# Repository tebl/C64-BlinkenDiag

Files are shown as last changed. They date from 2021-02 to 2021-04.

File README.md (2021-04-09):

# C64 BlinkenDiag
I was halfway through sketching out a new PCB based on the details found in an article on [tech.guitarsite.de](http://tech.guitarsite.de/c64_diag_dt_cart.html) before realizing it was already a PCB mentioned at the bottom, more specifically the one by [Diag64cart](https://github.com/svenpetersen1965/Diag64cart) by Sven Petersen (in turn based on [VersaCart64](https://github.com/bwack/Versa64Cart). I did however choose to introduce a few simple features of my own, mainly adding the option of disabling ROM boot - the method used was based on details found on [markus.brenner.de/cartridge](http://markus.brenner.de/cartridge). Secondly, I added a lot of LEDs in the hope that it might in some way be used to detect bus errors.

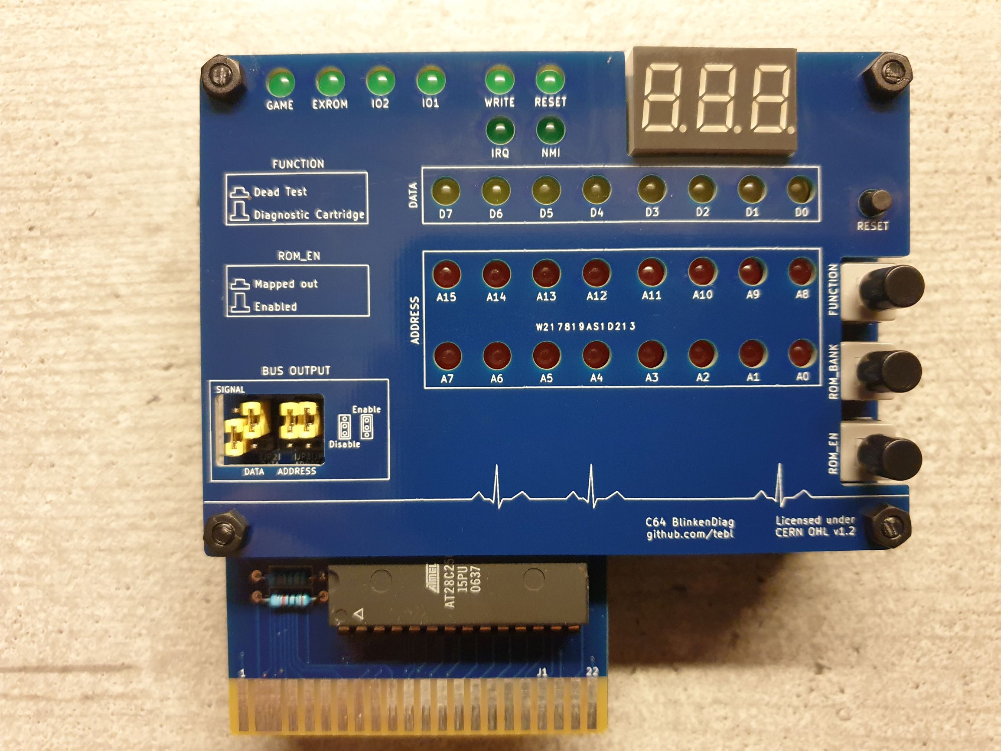
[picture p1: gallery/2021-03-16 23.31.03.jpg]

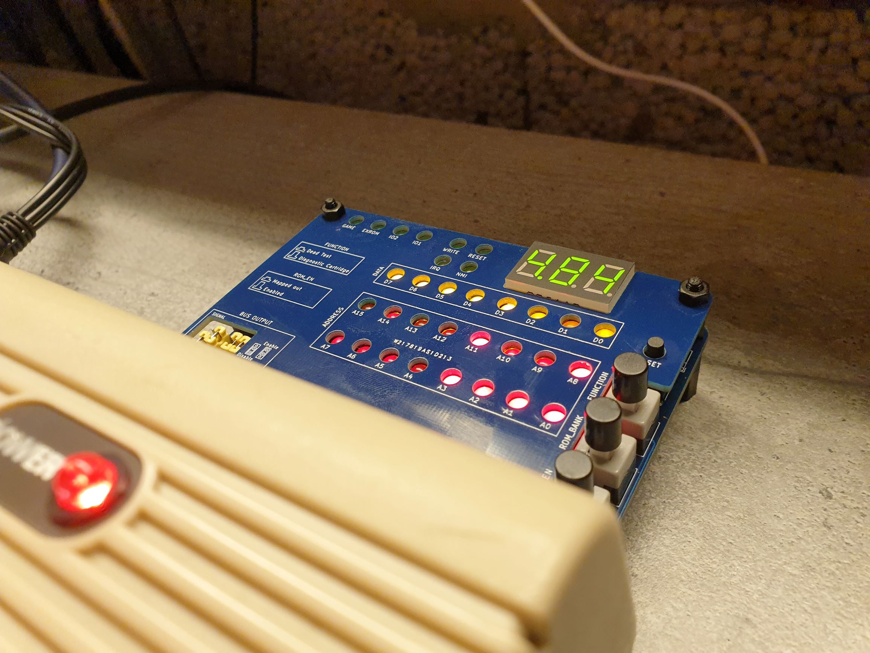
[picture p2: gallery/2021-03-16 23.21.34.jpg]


- [1> Building the unit](#1-building-the-unit)
  - [1.1> Soldering it together](#11-soldering-it-together)
  - [1.2> Assembling the unit](#12-assembling-the-unit)
  - [1.3> Testing it out](#13-testing-it-out)
- [2> Schematic](#2-schematic)
- [3> BOM](#3-bom)

# 1> Building the unit
Building the unit assumes you have at least minor experience soldering things together, recommended is at least a soldering station with adjustable temperature to get started - usually you'll want some 60/40 solder tin (if you can get that where you live). With the equipment sorted, now comes the shopping. So head on over to the [BOM](#3-bom)-section for some information on what you need, with ebay, AliExpress and similar sites you'll need to treat these as a starting search term and get what seems to match the gallery pictures.

## 1.1> Soldering it together
Every part already accounted for? Good, then let's start by not burning the house down (unless it obviously has more than one snake in it). Start by soldering in the resistors, there should only be a few of these on the board - follow it all up by tackling the resistor networks onto the boards, these are all the same type and you should match up the dot on them with the square hole. If you want to install sockets for all of the ICs, then that is good - if not, then please reconsider your life choices about now. Sockets need to match up with the markings on the PCB, indent on the socket should match the half-moon indent on the PCB (use machined sockets if you like that sort of thing).

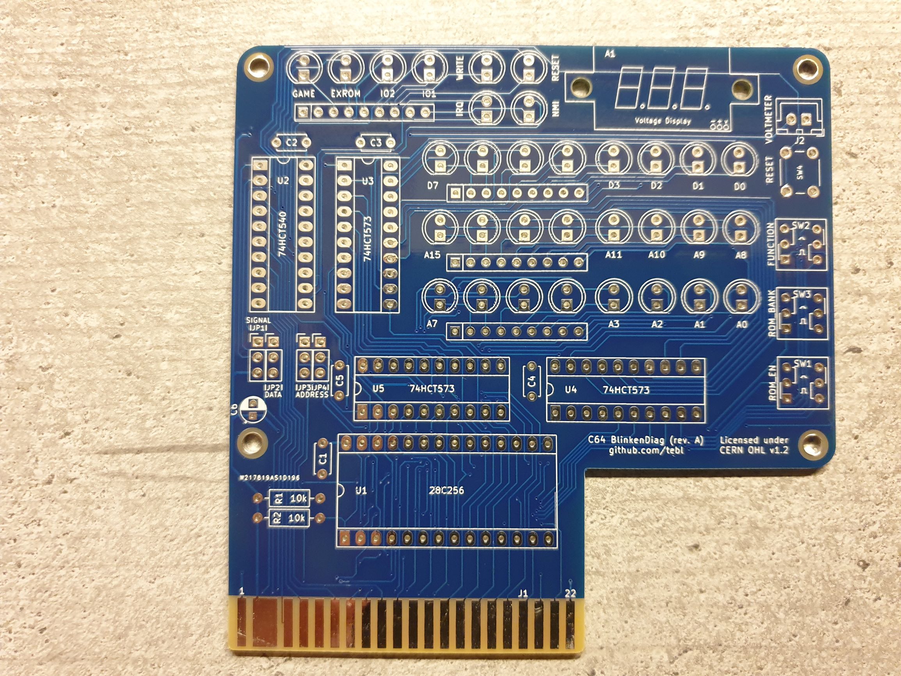
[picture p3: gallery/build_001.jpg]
Build 001


Add the capacitors that are next to the sockets, these are only for decoupling and are not of the kind that is polarized - personally I tend to solder them in so that, if possible, you can see the printing on the side. The electrolytic capacitor on the bottom left corner, but we need to check that we have a component that will fit first - the faceplate will sit 8mm above the main PCB. If you have one that won't fit, you can lay it on its side instead of waiting for the slow boat from China. Note that this component is polarized, what this means is that you need to match the stripe with the filled in white space on the silkscreen.

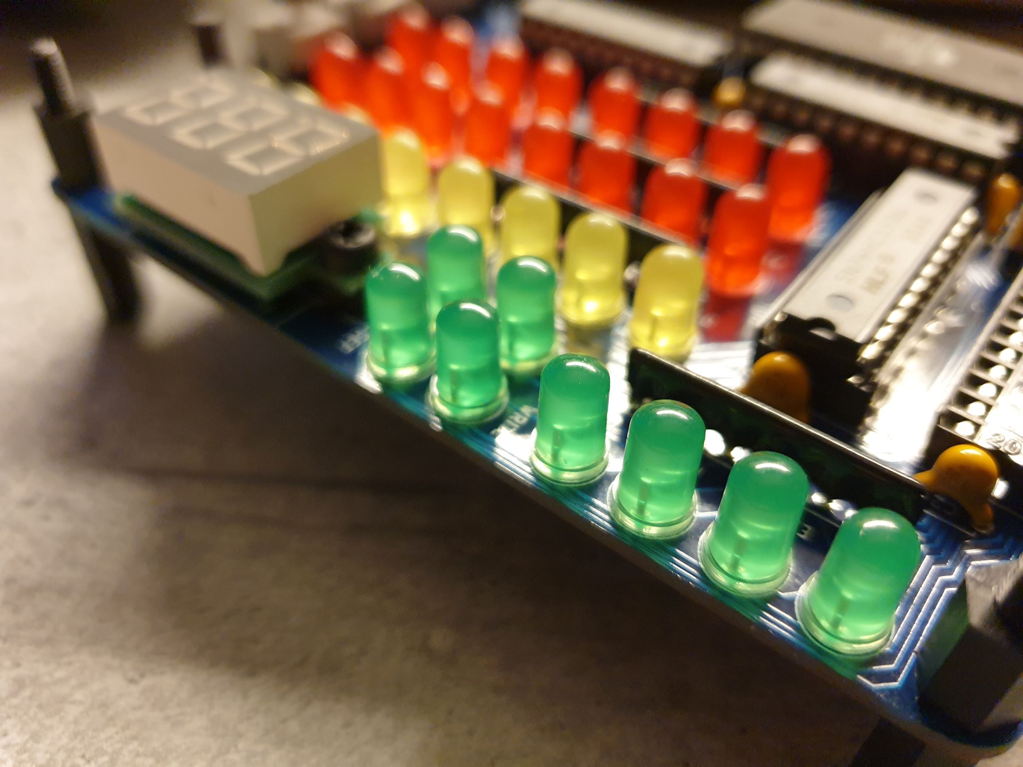
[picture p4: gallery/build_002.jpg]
Build 002


Now we need to start the long and arduous task of soldering in all of those LEDs, but before we can do so - you  should probably check that they all work, the easiest way is to just use a CR2032 battery and putting it between the legs of the LED. Testing them will avoid soldering in one that is significantly more dim than the rest, especially if you originally got a whole shopping bag full of them for a single Dollar, Euro, Pound or whatever it is you usually fling at shopping attendants (please don't actually do this). One of the legs is called an anode and the other a cathode, but I can never remember which is which - so I'll just say that the short pin goes into the square hole. Only solder on one of the pins, then flip the board over again and heat up the pin by using your finger to push it flush against the board - this ensures that the faceplate will fit properly and you won't have a board where everything looks crooked.

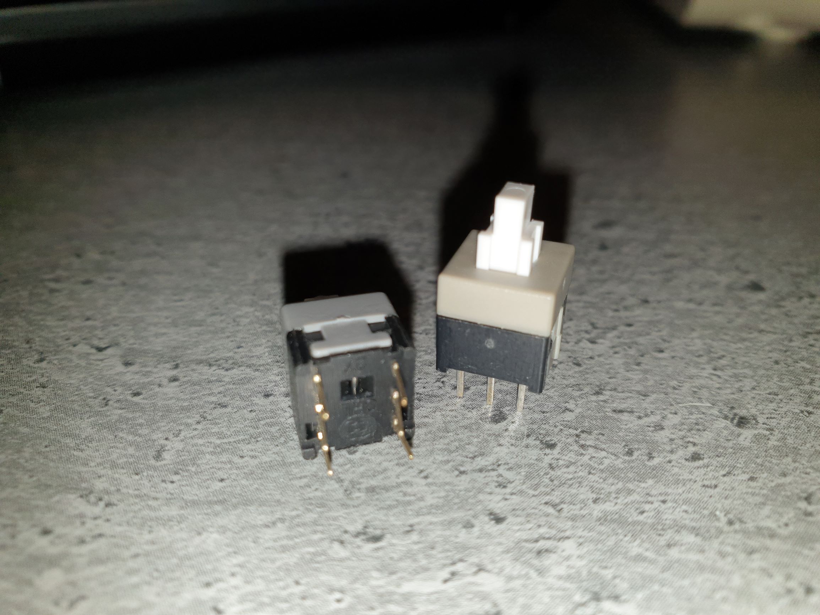
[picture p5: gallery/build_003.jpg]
Build 003


SW1, 2 and 3 are a common AliExpress variety of DPDT 6-pin switches that needs some further explenation. The ones I've used here have a black base, the ones with a different colour will unfortunately not work as the pinouts have been shuffled around so ensure that you have the correct one ready to go. There is a square hole on the bottom that can be matched to the PCB illustration, just make sure that it goes into place with the hole at the top. There are also some keycaps floating around, but these fit rather loosely and I've taken to adding a drop of glue on the top of the switch to ensure that it doesn't go flying off. The reset switch is a more common momentary switch, the only requirement is that it is long enough to poke through the faceplate (6x6x9mm should fit, get a larger one if you require a bit than just barely).

## 1.2> Assembling the unit
Insert ICs into the sockets as indicated, ensuring that the indent matches the orientation on the board - plugging them in the wrong way ensures that you'll have to order some more. Double-check before even considering plugging it into something, use the picture below as reference. Even more important, study the board under good lighting condition in order to determine whether any stray blobs of solder has ended up in the wrong place - you're supposed to fix your C64, not add to its growing list of problems!

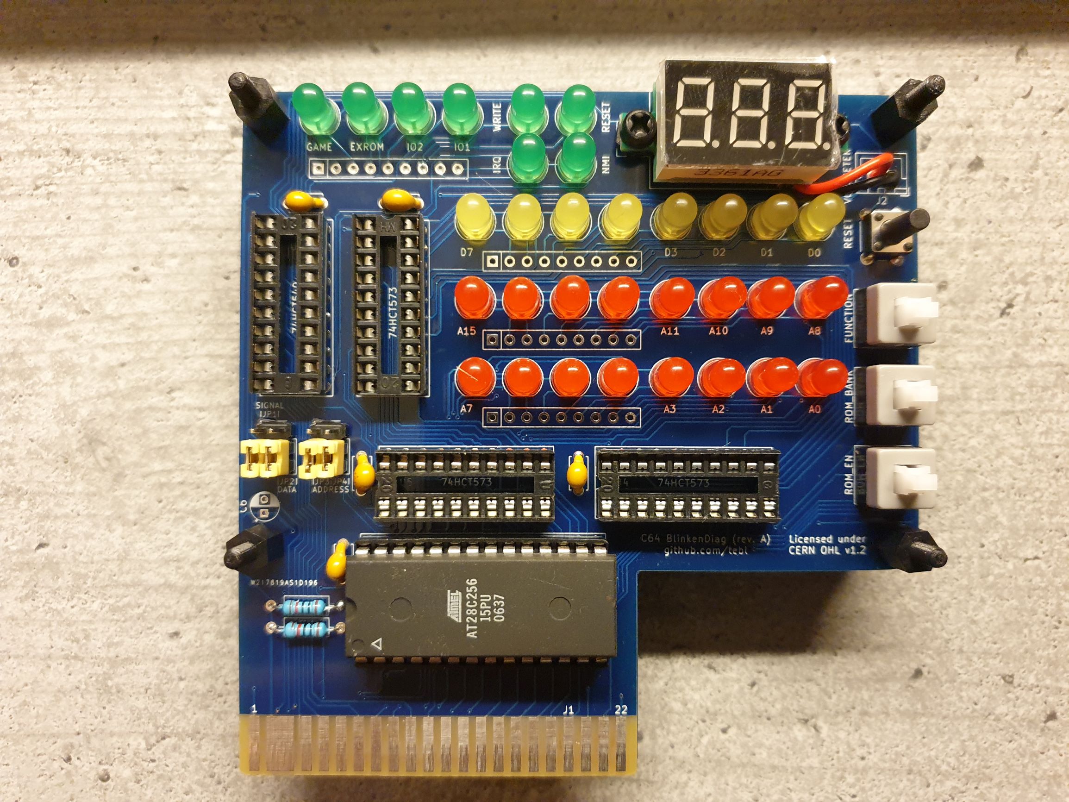
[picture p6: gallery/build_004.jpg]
Build 004


At this point I've not mentioned the EEPROM socket - it is designed for a 28C256, not 27C256 as used in many similar designs (mainly because I hate using UV to erase things and I have enough of them). You'll need an EPROM Programmer to put the machine code onto the chip, the one I use is one of the cheaper options - the MiniPro TL866. Using the *MiniPro Programmer* software (or similar), click the button below *Select IC* and search for 28C256 - find the relevant manufacturer for the chips you have and select the exact chip name. Using *File --> Open...*, browse to a suitable HEX-file such as the one found in the software section of this project (ensure that you download the raw version of this file, not just right click and save as on the github page - as that would save a bunch of html instead of the actual file). Just use the default options for the dialog, then flash the contents into the chip using *Device --> Program*. If this fails, either on write or verification - recheck that you have the correct chip specified, alternatively try another one as ebay chips usually have one or two out of 10 that simply don't work.

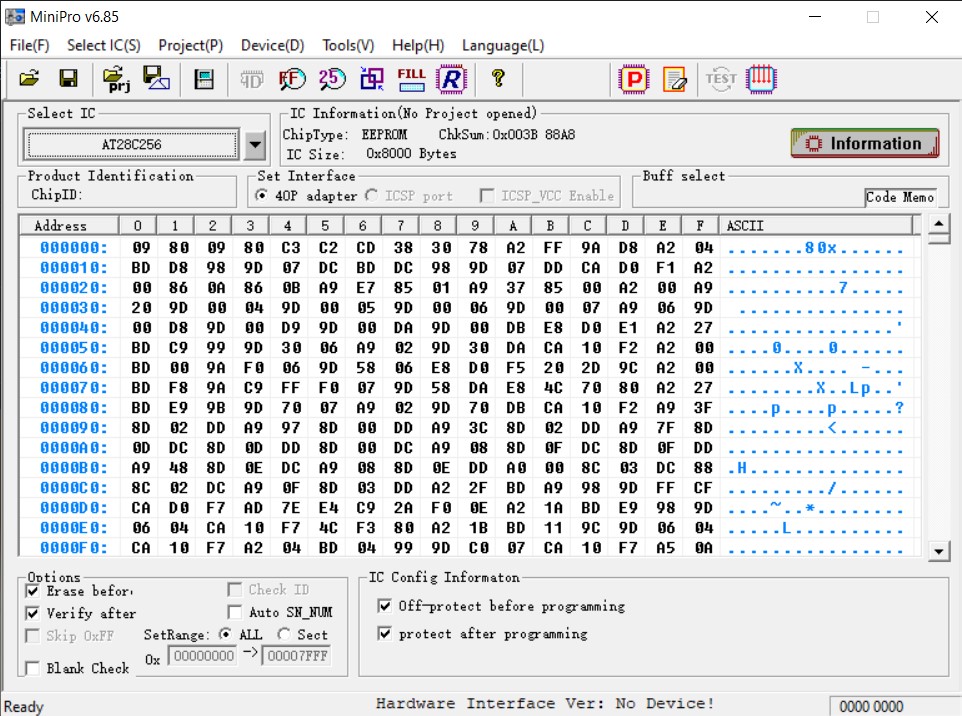
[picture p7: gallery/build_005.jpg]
Build 005


The board when plugged into a C64 would more than likely hang out of the connector at an angle, if not 3d-printing a base then I recommend adding some M3 nylon hex standoffs to the bottom of the unit (these should be approximately 16mm in height, alternatively you can combine two 8mm standoffs instead to get the same height) - these can either be F-F or M-F depending on what you have available. The cutouts for LEDs and switches have been designed for a spacing of 8mm between the main module and the faceplate, this should screw onto the 16mm ones you just installed on the bottom. Screw the faceplate onto the main module using standard M3x6mm nylon screws.

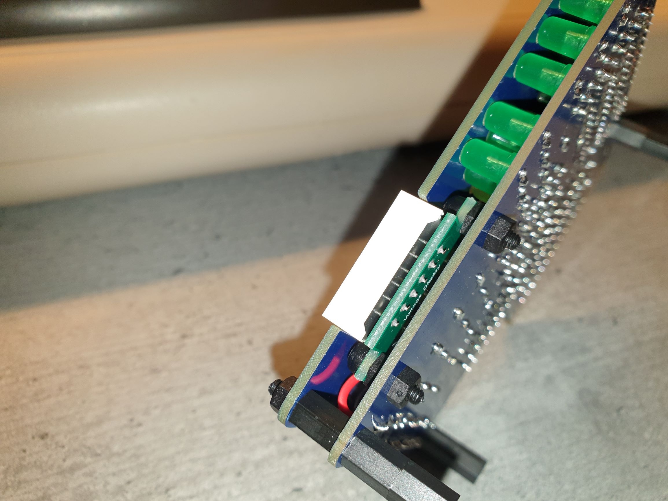
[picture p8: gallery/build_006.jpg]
Build 006


The voltmeter module, helpfully only coming with the text *voltage display* printed on them can be installed into the space allotted for it (I picked these up listed as a 0.36" voltage display module in various colours). It has wires sticking out of the bottom, so for the mounting I suggest using some longer M3 nylon screws and adding a nut directly below the module - then installing it on the board, adding two more nuts on the bottom of the main PCB to hold it into place.

## 1.3> Testing it out
With all of the jumpers in their default position, meaning LED outputs are disabled, and the SPDT switches in their upper position - you should get a standard *Diagnostic Cartridge*. Put the **FUNCTION** switch in the lower position and you should get the normal dead test. **ROM_BANK**, when in its lower position will get you a different set of diagnostic tools - depending on the images you flashed your EEPROM with (I specified a 28C256 EEPROM for ease of changing out the contents).

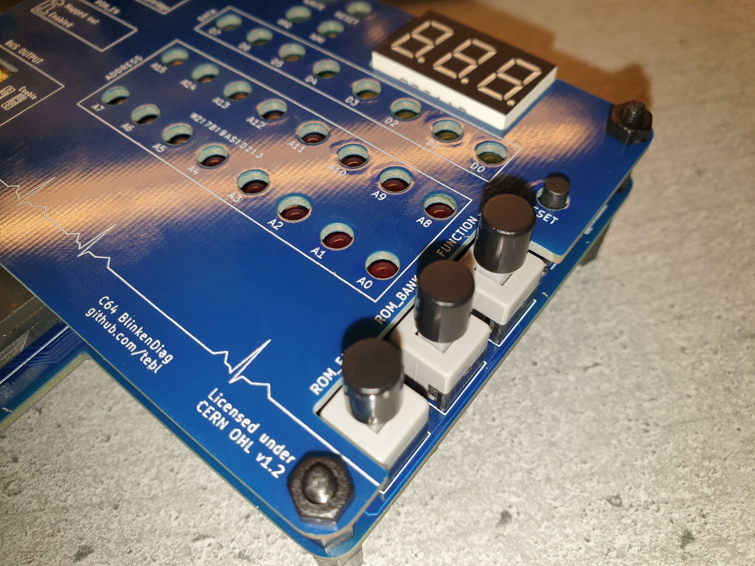
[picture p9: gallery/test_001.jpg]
Test 001


The final switch, labelled **ROM_DIS**, allows you to disable the cartridge detection routines in the C64 - similar to what is done with common cartridge expanders. When pushed the EEPROM is still electrically connected to the C64, but the PLA won't allow the C64 to boot from it - this is here so that you can observe the LED outputs on the machine, while still booting to the standard C64 bootup screen.

# 2> Schematic
The supplied KiCad files should be sufficient as both a schematic and as a  starting point for ordering PCBs (basically you could just zip the contents of the export folder and upload that on a fabrication site), the schematic is also available in [PDF-format](documentation/schematic) and this is what you'll need to print and work your way through this things don't work as expected after assembly.

# 3> BOM
Most parts should be easy to get a hold of from your favourite local electronic component shop, but given that I don't have access to such shops where I live so everything was based on whatever I could get cheapest from eBay/AliExpress (free shipping, but plan on waiting 3-4 weeks for delivery). Values listed in parenthesis are for features that are not required for basic cartridge functionality, but you should read through the section on [building the unit](#1-building-the-unit) to ensure that you're not missing out on anything cool. As always, plan on adding DIP-sockets in addition to the chips listed that have been listed.

| Reference | Item | Count | Order  |
| --- | --- | ----- | --- |
| PCB | Fabricate using Gerber files | 1 | [PCBWay](https://www.pcbway.com/project/shareproject/C64_BlinkenDiag.html)
| Faceplate PCB | Fabricate using Gerber files | (1)| [PCBWay](https://www.pcbway.com/project/shareproject/C64_BlinkenDiag__faceplate_.html)
| A1 | 0.36" Digital Voltmeter Module | (1)|
| C1 | 100nF ceramic capacitor (5mm pin spacing) | 1 |
| C2-C5 | 100nF ceramic capacitor (5mm pin spacing) | (4)|
| C6 | 10uF 25v electrolytic capacitor (2mm pin spacing) | (1)|
| D1-D32 | 5mm LED, preferably non-clear variety | (32)|
| JP1-JP4 | Male breakable pin header (3 pins) | (4)|
| JP1-JP4 Jumpers  | 2.54mm pin header jumper (long type when used with faceplate)  | (4)|
| R1,R2 | 10k ohm resistor | 2 |
| RN1-RN4 | A331J 8x 330 ohm resistor network (SIP-9) | (4)|
| SW1-SW3 | 6pin 8.5mm x 8.5mm latching switch | 3 |
| SW4 | 6x6x8mm momentary switch | (1)|
| U1 | 28C256 EEPROM (DIP-28) | (1)|
| U2 * | 74HCT540 (DIP-20), or 74HCT541 for non-inverting option | (1)|
| U3-U5 | 74HCT573 (DIP-20) | (3)|
| Mounting ** | M3x8mm nylon HEX standoff (F-F) | (4)|
| Mounting ** | M3x16mm nylon HEX standoff (M-F) | (4)|
| Mounting ** | M3x6mm nylon screw | (4)|
| Mounting ** | M3 nylon nut | (4)|
| Mounting *** | M3 nylon nut | (4)|
| Mounting *** | M3x10mm nylon screw | (2)|

*) Quite a lot of the CPU signals are active low, the 74HCT540 will invert these signals so that the LED instead lights up when they are active. If you want these to reflect the actual signal, use the non-inverting variant of the chip instead (74HCT541).

**) The standoffs specified are the exact sizes required, but note that you could stack these to obtain the size you need - 8mm + 8mm usually equals 16mm (meaning you only need about 12 of them). Instead of buying the F-F standoffs separately, you could just cut off the screw part on the very bottom.

***) These are used to mount the voltmeter module, an extra nut is used between the module and PCB to avoid destroying the wires underneath the module.

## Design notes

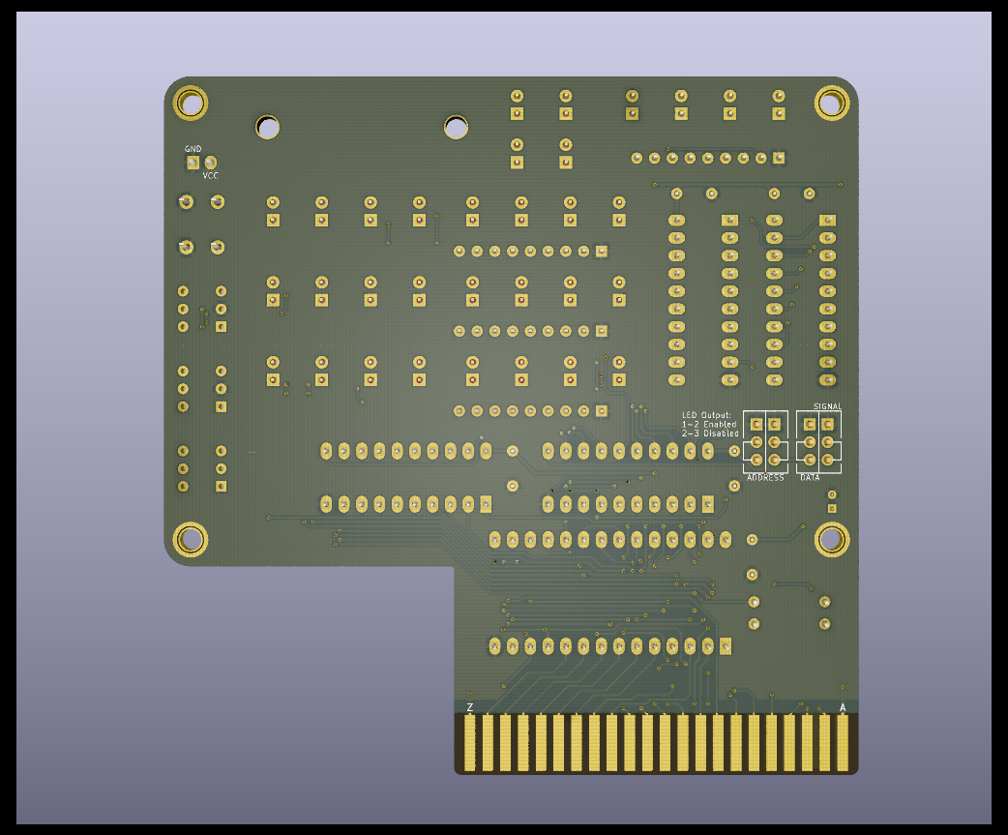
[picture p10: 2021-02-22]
gallery/C64 BlinkenDiag2.png

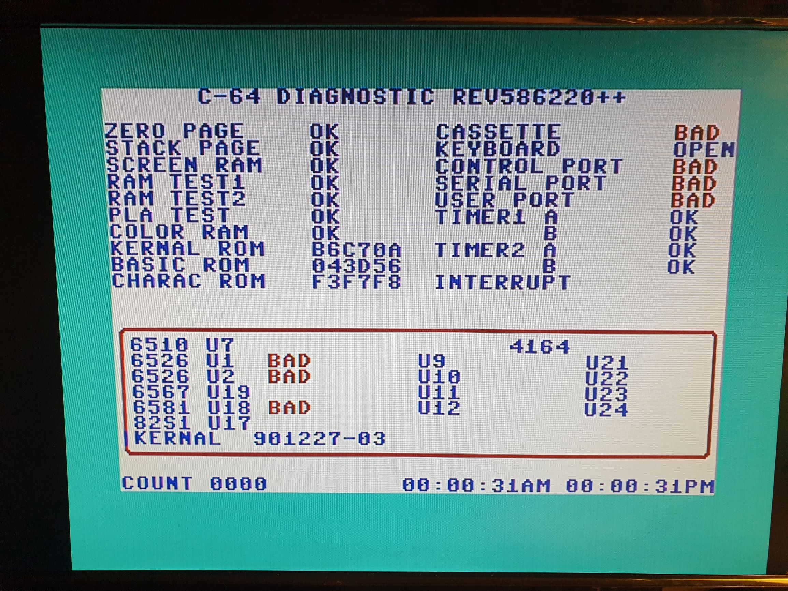
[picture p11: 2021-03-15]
gallery/2021-03-15 01.37.37.jpg

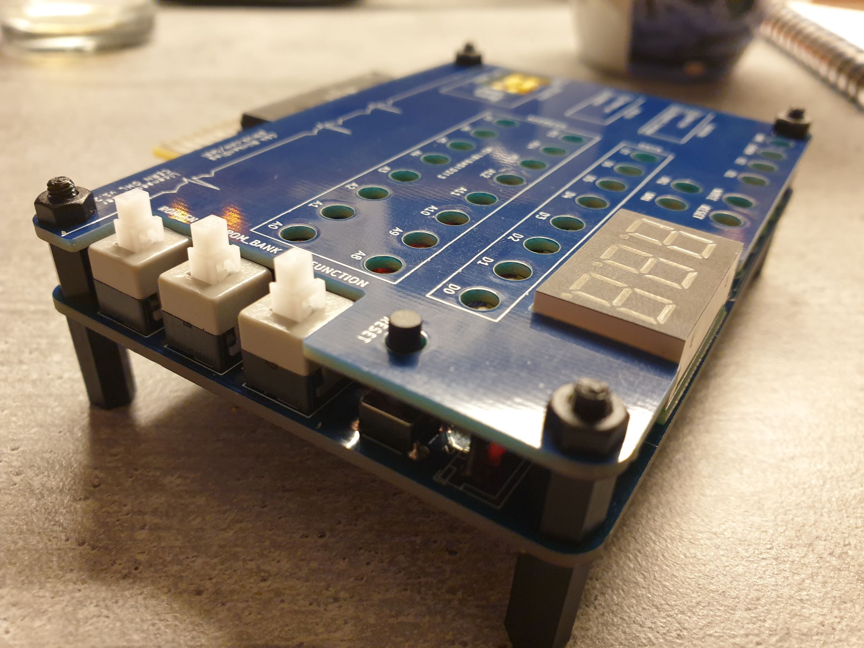
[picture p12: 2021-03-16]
gallery/2021-03-16 19.03.23.jpg

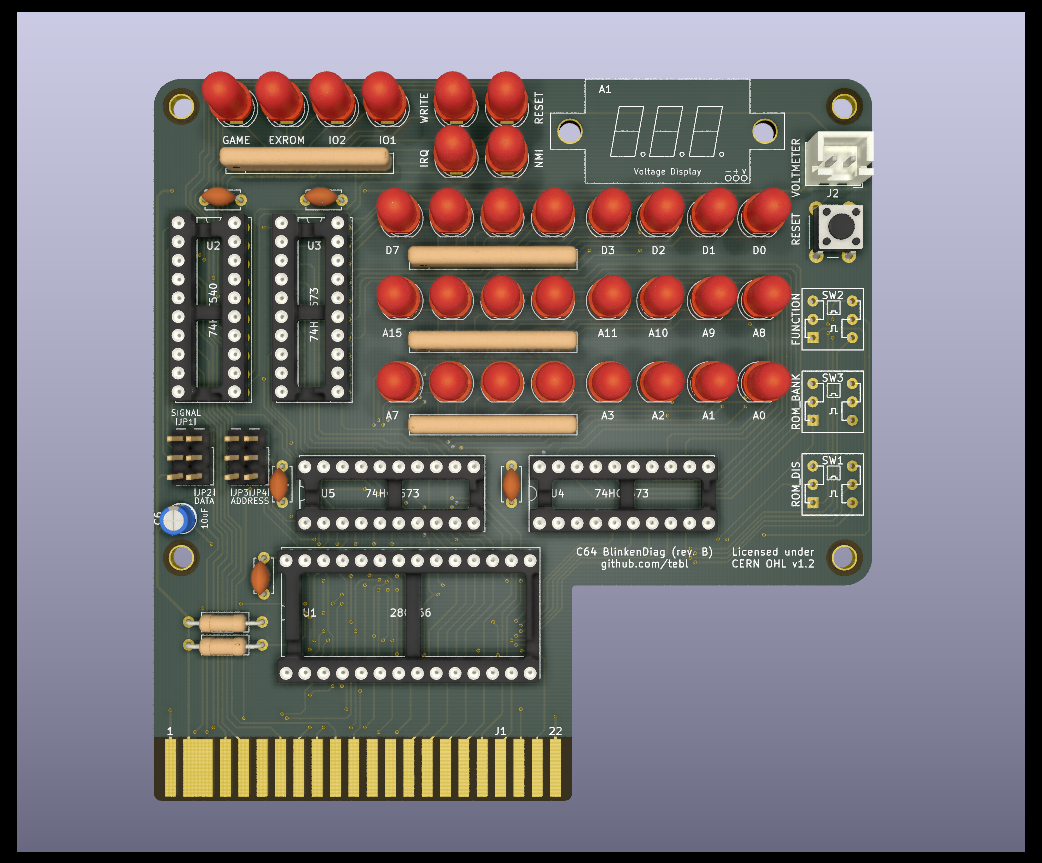
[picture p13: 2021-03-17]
gallery/C64 BlinkenDiag.png

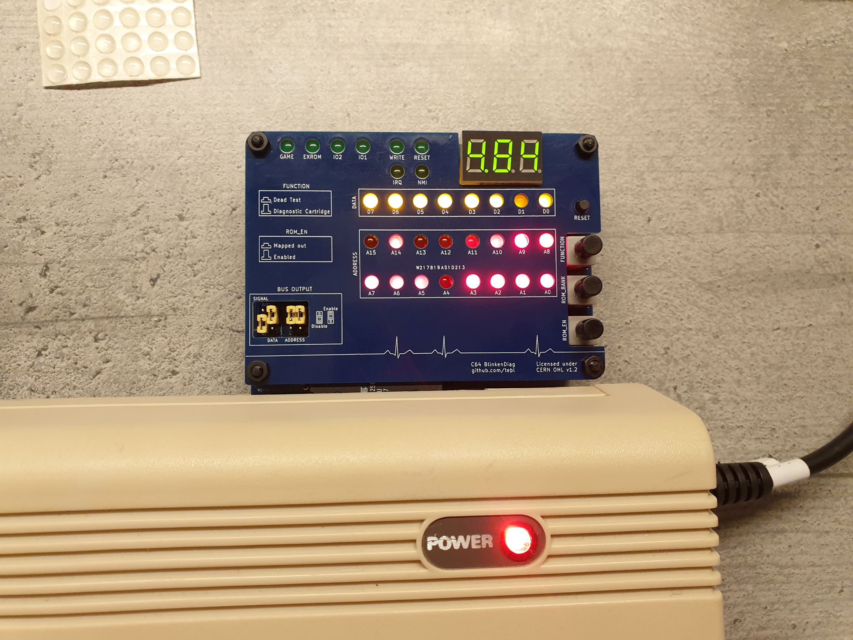
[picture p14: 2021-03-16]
gallery/2021-03-16 20.57.16.jpg

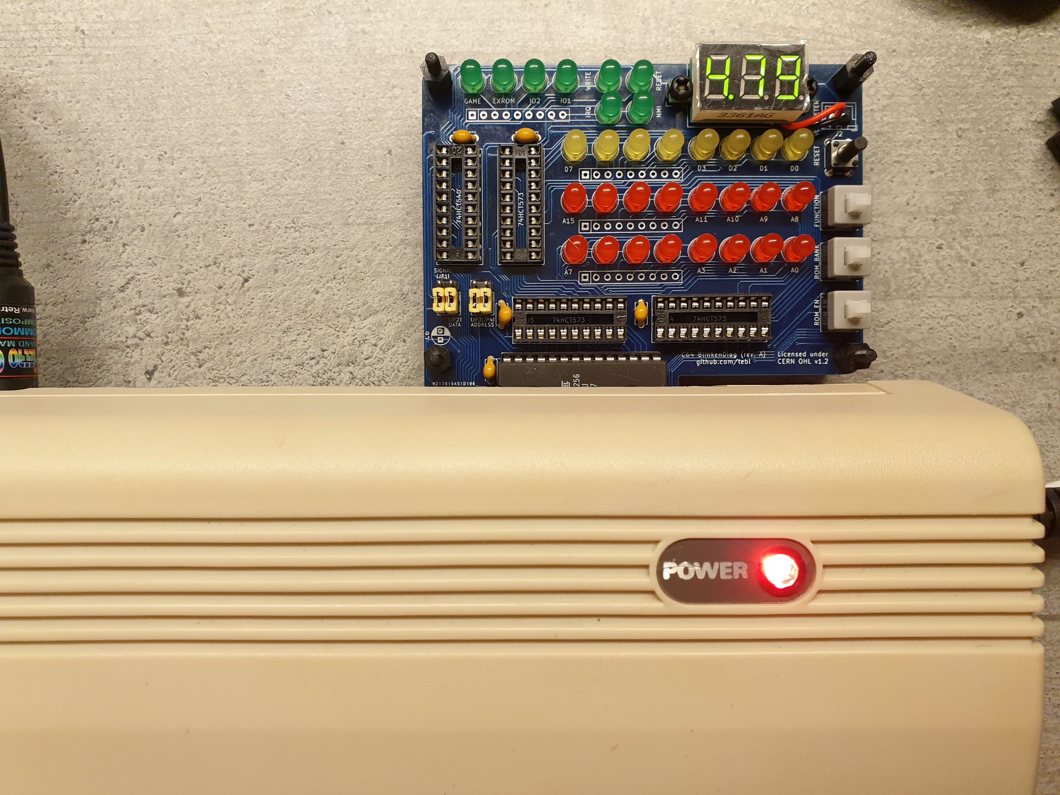
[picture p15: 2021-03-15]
gallery/2021-03-15 01.37.31.jpg

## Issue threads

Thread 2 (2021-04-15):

Function switch

TMO2018, 2021-04-15:
The BlinkenDiag (rev B) does not work when the FUNCTION switch is pressed and remains in RESET. GAME is activated. I swapped the Eeprom and the switch and checked the wiring and couldn't find any faults. Do you have any idea?
I've tested on a 407 and 469 board.

tebl, 2021-04-15:
I'm not sure, it shouldn't stay in reset. Does that mean you've tested it
and the reset is actively held low, as measured with multimeter, or just
that it fails to boot?

The biggest gotcha is usually the switches, they seem to have a different
pinout depending on the colour on the bottom of them (it should be black).
Preferably, test with multimeter to see that they're working as indicated
on the silkscreen.

Also check that it isn't mounted upside down, I seem to remember this made
a difference on a previous build though I might be remembering the wrong
switch.

tor. 15. apr. 2021, 20:35 skrev TMO2018 ***@***.***>:

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

TMO2018, 2021-04-16:
I tested the switches with a multimeter and they corresponded to the function of the circuit diagram. The switches have a black base and a light gray top.
I have measured the conductor tracks to the expansion port and Eeprom including the different switch positions and it looks right.
When the function switch is pressed, the C64 remains stuck in reset. The reset LED lights up constantly, just like the game LED (U2: 74ACT540). The same behavior with a 74HCT541, but with inverted LEDs.
The Kernals C64-Diag and 1541-Diag always work. At first, deadtest and stid deadtest did not work. Then only once and then never again. I haven't been able to reproduce this behavior until now. That's what I'm a little confused about right now.
When I try a CHECK64 module, all four tests work (Deadtest, C64-Diag, 1541-Test, C128-Diag).

tebl, 2021-04-18:
The function switch mainly just switches around two of the signals, so they
shouldn't really affect the reset line. GAME and RESET are both present on
U2, pins 2 and 3, so at this point they are next to each other and there
might be a small bridge there.

If you have another set of PCBs, it helps to have it next to you when
troubleshooting - makes it easier to beep out which things are on the PCB
and which are in contact due to the components.

fre. 16. apr. 2021, 10:43 skrev TMO2018 ***@***.***>:

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

TMO2018, 2021-04-18:
I will get a second board in the next few days and will continue to search for the error. Thank you for your assistance.

TMO2018, 2021-04-18:
I found the error thanks to your reference to pins 2 and 3 of U2. I unsoldered the IC socket from U2. The dead test works without the IC socket. I could hardly believe it, but there was an electrical connection between pins 2 and 3 in the unsoldered IC socket. I couldn't see it with my eyes. I soldered in a new socket and now the cartrige works as expected. Thank you for your support. That was very helpful.

tebl, 2021-04-18:
That's awesome 😀

søn. 18. apr. 2021, 19:11 skrev TMO2018 ***@***.***>:

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

Closed 2021-04-18.

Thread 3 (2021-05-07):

Switch Pinout

MarkusPlehn, 2021-05-07:
Hi, thanx for this Projekt.
I struggle with the 6pin Switches. Could you please specify the pinout of the correct Switch? Is the middle Pin the COM and it Switches to left and right? So Pin 2 is the middle, Pin 1 left and Pin 3 right?

tebl, 2021-05-07:
It should be one with a black base like in this picture:
https://raw.githubusercontent.com/tebl/c64-blinkendiag/main/gallery/build_003.jpg

On the underside there's a square hole further towards one side, this
should be towards the top of the board. The article linked below should go
into further detail, if you should need it.

https://www.hackster.io/UtkarshVerma/6-pin-push-switch-working-7bb5ef

fre. 7. mai 2021, 17:08 skrev Markus_64 ***@***.***>:

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

Closed 2022-02-14.

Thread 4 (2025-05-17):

Easier way to solder 32 LEDs straight

yaddanadda, 2025-05-17:
In your instruction, you stated "only solder on one of the pins, then flip the board over again and heat up the pin by using your finger to push it flush against the board - this ensures that the faceplate will fit properly and you won't have a board where everything looks crooked."

There's an easier way if one has the faceplate and the hex mounting hardware. Put all 32 LEDs without soldering, then mount the faceplate and secure them. They will align itself to the holes on the faceplate and be straight, plus the faceplate will hold all of the LEDs in place when you flip the board to solder them all.

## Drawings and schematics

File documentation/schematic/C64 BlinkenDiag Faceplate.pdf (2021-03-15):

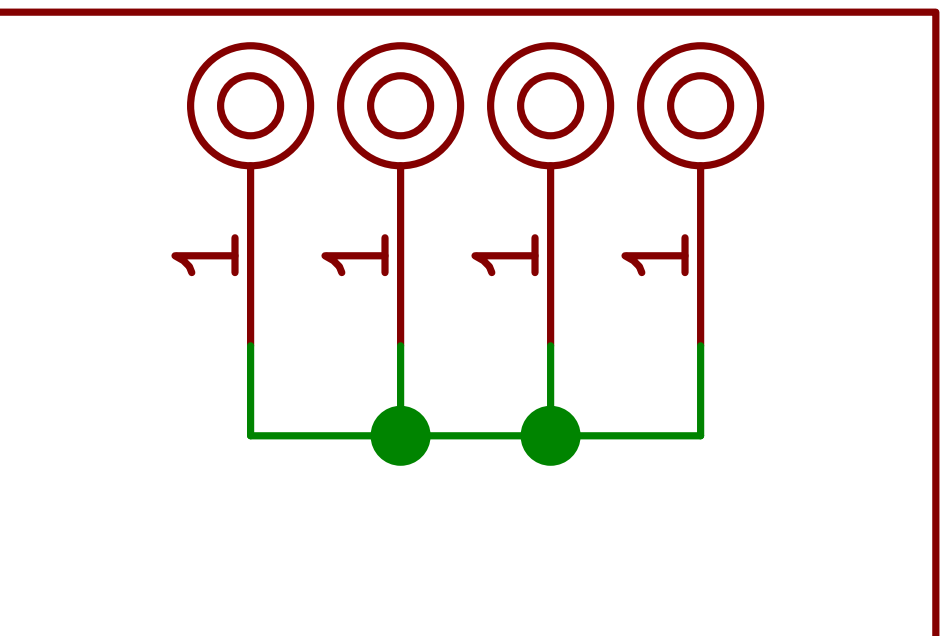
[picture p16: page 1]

It's just a faceplate, almost nothing to see here.

File: C64 BlinkenDiag Faceplate.sch Sheet: /
Id: 1/1 Title: C64 Blinkenlight Diagnostic (Faceplate)

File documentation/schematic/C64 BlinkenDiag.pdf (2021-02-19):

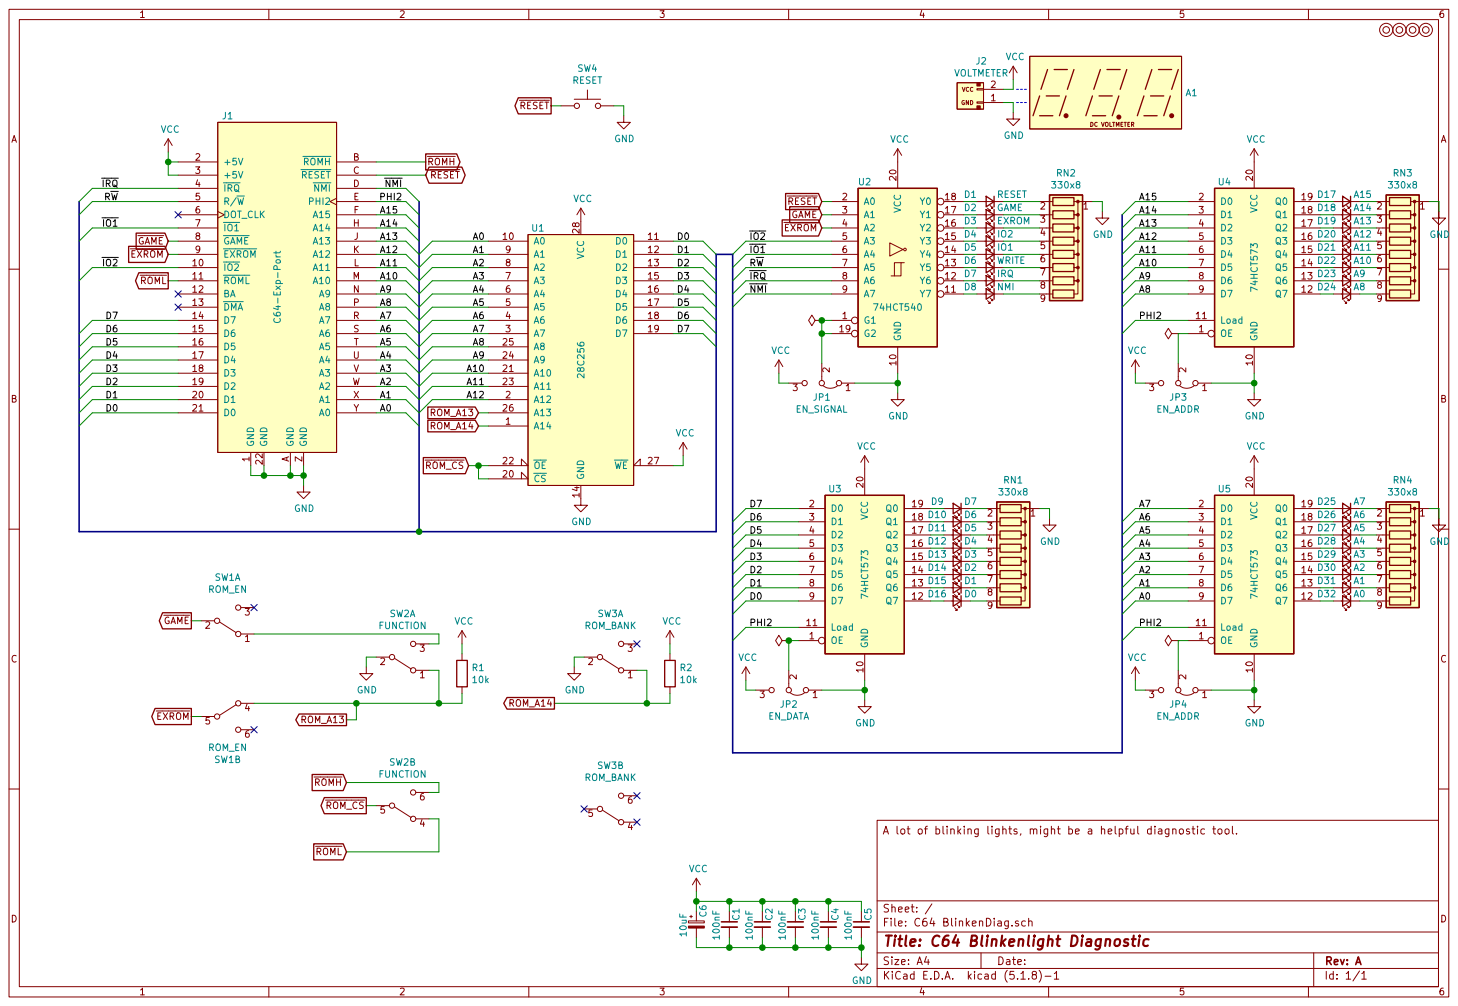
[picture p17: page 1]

File: C64 BlinkenDiag.sch Sheet: / A lot of blinking lights, might be a helpful diagnostic tool.

Id: 1/1 Title: C64 Blinkenlight Diagnostic

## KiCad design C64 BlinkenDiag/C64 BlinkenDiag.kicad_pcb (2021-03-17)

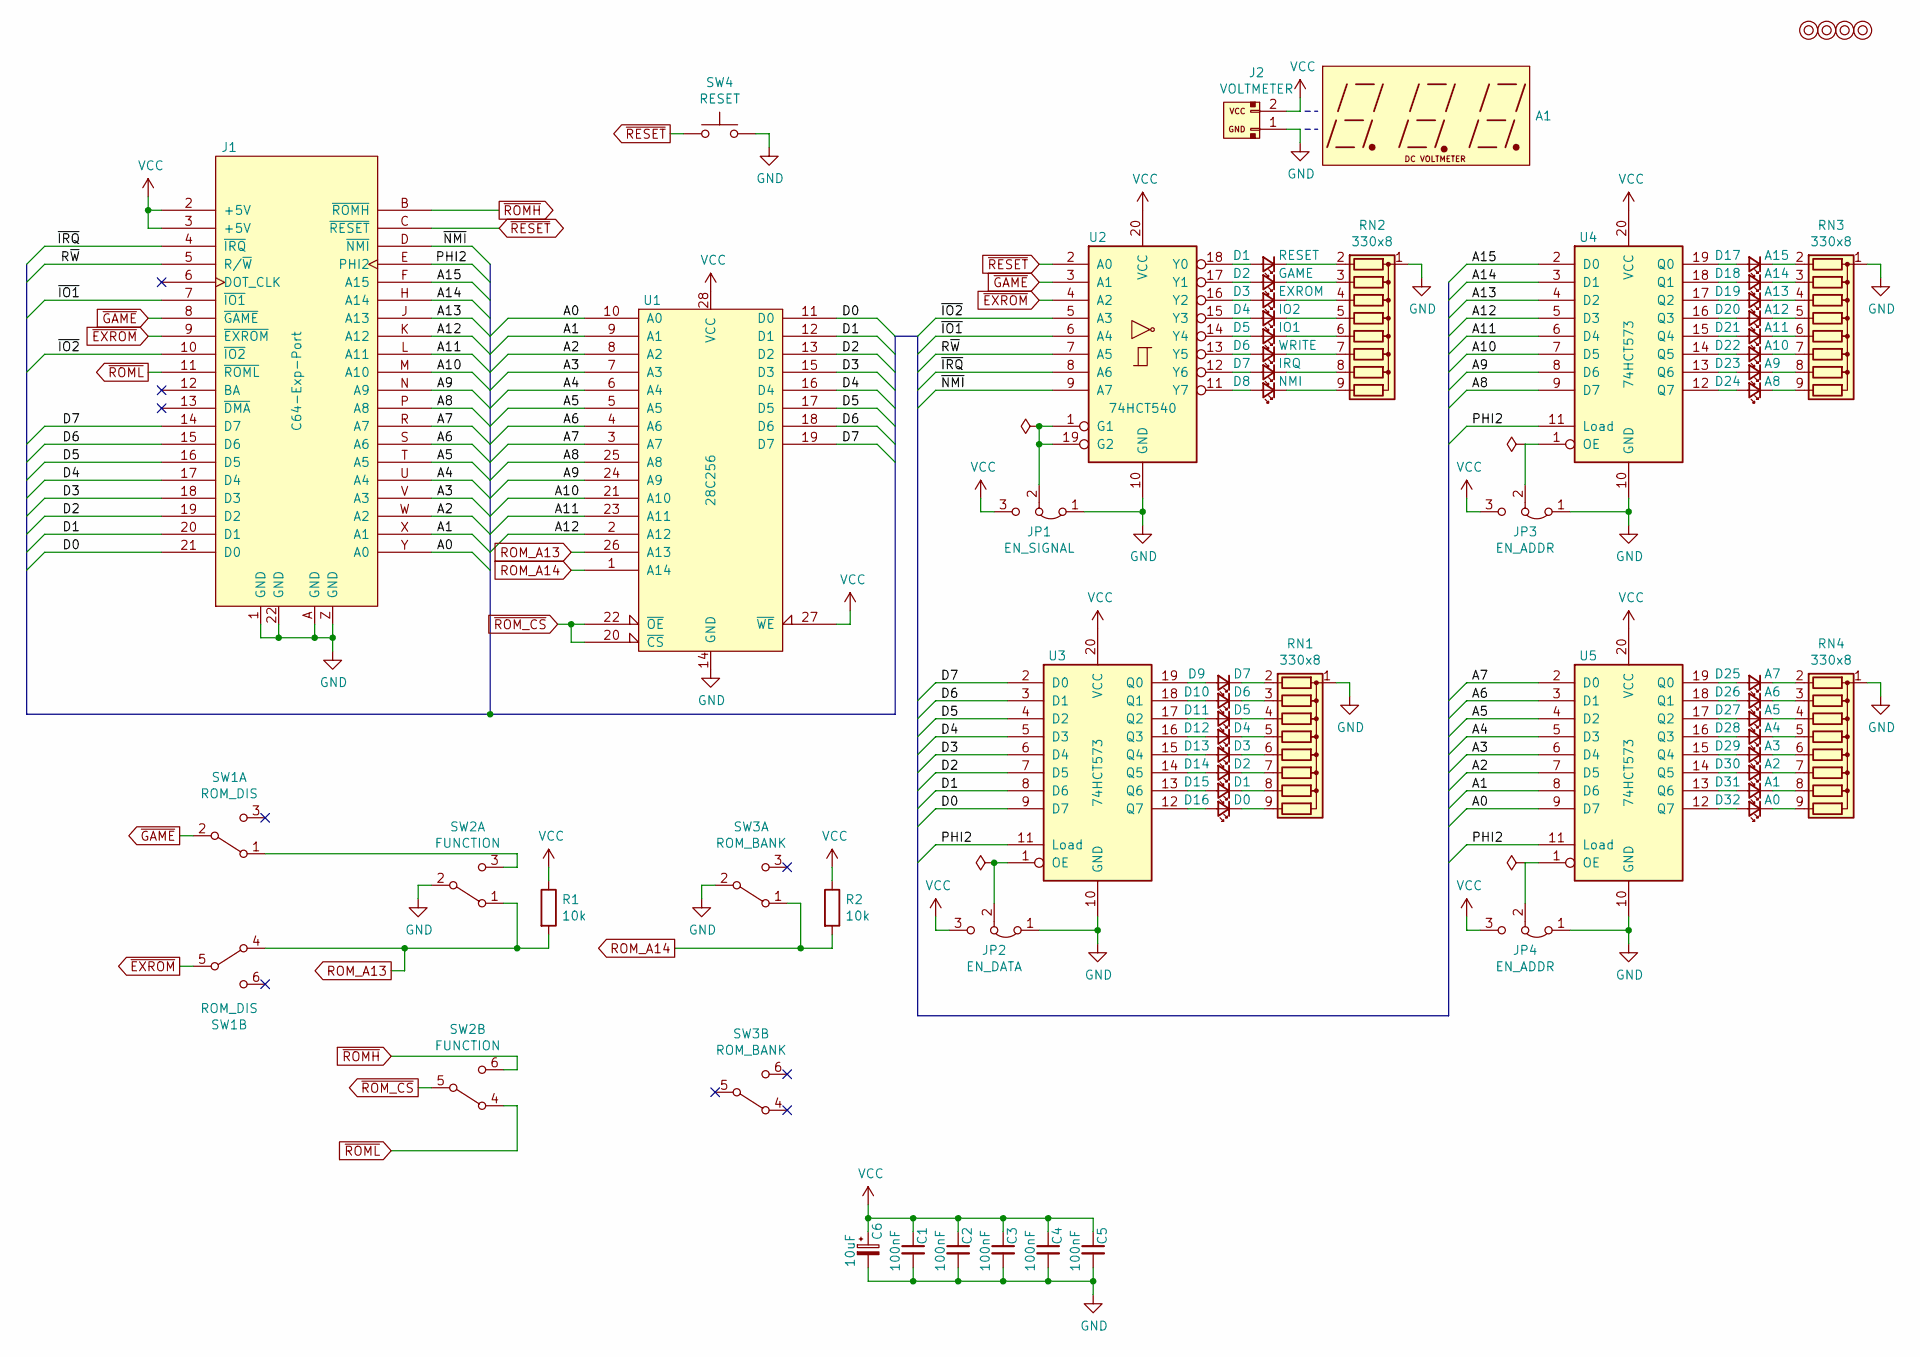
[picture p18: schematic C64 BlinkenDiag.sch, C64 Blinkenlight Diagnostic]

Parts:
A1: module; voltage_display_036
C1, C2, C3, C4, C5: 100nF; C_Disc_D4.7mm_W2.5mm_P5.00mm
C6: 10uF; CP_Radial_D4.0mm_P2.00mm
D1: RESET; LED_D5.0mm
D2: GAME; LED_D5.0mm
D3: EXROM; LED_D5.0mm
D4: IO2; LED_D5.0mm
D5: IO1; LED_D5.0mm
D6: WRITE; LED_D5.0mm
D7: IRQ; LED_D5.0mm
D8: NMI; LED_D5.0mm
D9: D7; LED_D5.0mm
D10: D6; LED_D5.0mm
D11: D5; LED_D5.0mm
D12: D4; LED_D5.0mm
D13: D3; LED_D5.0mm
D14: D2; LED_D5.0mm
D15: D1; LED_D5.0mm
D16: D0; LED_D5.0mm
D17: A15; LED_D5.0mm
D18: A14; LED_D5.0mm
D19: A13; LED_D5.0mm
D20: A12; LED_D5.0mm
D21: A11; LED_D5.0mm
D22: A10; LED_D5.0mm
D23: A9; LED_D5.0mm
D24: A8; LED_D5.0mm
D25: A7; LED_D5.0mm
D26: A6; LED_D5.0mm
D27: A5; LED_D5.0mm
D28: A4; LED_D5.0mm
D29: A3; LED_D5.0mm
D30: A2; LED_D5.0mm
D31: A1; LED_D5.0mm
D32: A0; LED_D5.0mm
J1: C64-Exp-Port; C64_Expansion_Port
J2: VOLTMETER; JST_XH_B2B-XH-A_1x02_P2.50mm_Vertical
JP1: EN_SIGNAL; PinHeader_1x03_P2.54mm_Vertical
JP2: EN_DATA; PinHeader_1x03_P2.54mm_Vertical
JP3, JP4: EN_ADDR; PinHeader_1x03_P2.54mm_Vertical
M1, M2, M3, M4: Mounting; M3_pin
R1, R2: 10k; R_Axial_DIN0207_L6.3mm_D2.5mm_P10.16mm_Horizontal
RN1, RN2, RN3, RN4: 330x8; R_Array_SIP9
SW1: ROM_DIS; dpdt_switch_black
SW2: FUNCTION; dpdt_switch_black
SW3: ROM_BANK; dpdt_switch_black
SW4: RESET; SW_PUSH_6mm
U1: 28C256; DIP-28_W15.24mm_Socket_LongPads
U2: 74HCT540; DIP-20_W7.62mm_Socket_LongPads
U3, U4, U5: 74HCT573; DIP-20_W7.62mm_Socket_LongPads

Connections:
/A0: J1.Y (A0), U1.10 (A0), U5.9 (D7)
/A1: J1.X (A1), U1.9 (A1), U5.8 (D6)
/A2: J1.W (A2), U1.8 (A2), U5.7 (D5)
/A3: J1.V (A3), U1.7 (A3), U5.6 (D4)
/A4: J1.U (A4), U1.6 (A4), U5.5 (D3)
/A5: J1.T (A5), U1.5 (A5), U5.4 (D2)
/A6: J1.S (A6), U1.4 (A6), U5.3 (D1)
/A7: J1.R (A7), U1.3 (A7), U5.2 (D0)
/A8: J1.P (A8), U1.25 (A8), U4.9 (D7)
/A9: J1.N (A9), U1.24 (A9), U4.8 (D6)
/A10: J1.M (A10), U1.21 (A10), U4.7 (D5)
/A11: J1.L (A11), U1.23 (A11), U4.6 (D4)
/A12: J1.K (A12), U1.2 (A12), U4.5 (D3)
/A13: J1.J (A13), U4.4 (D2)
/A14: J1.H (A14), U4.3 (D1)
/A15: J1.F (A15), U4.2 (D0)
/D0: J1.21 (D0), U1.11 (D0), U3.9 (D7)
/D1: J1.20 (D1), U1.12 (D1), U3.8 (D6)
/D2: J1.19 (D2), U1.13 (D2), U3.7 (D5)
/D3: J1.18 (D3), U1.15 (D3), U3.6 (D4)
/D4: J1.17 (D4), U1.16 (D4), U3.5 (D3)
/D5: J1.16 (D5), U1.17 (D5), U3.4 (D2)
/D6: J1.15 (D6), U1.18 (D6), U3.3 (D1)
/D7: J1.14 (D7), U1.19 (D7), U3.2 (D0)
/PHI2: J1.E (PHI2), U3.11 (Load), U4.11 (Load), U5.11 (Load)
/R~W: J1.5 (R/~W), U2.7 (A5)
/~IO1: J1.7 (~IO1), U2.6 (A4)
/~IO2: J1.10 (~IO2), U2.5 (A3)
/~IRQ: J1.4 (~IRQ), U2.8 (A6)
/~NMI: J1.D (~NMI), U2.9 (A7)
GND: C1.2, C2.2, C3.2, C4.2, C5.2, C6.2, J1.1 (GND), J1.22 (GND), J1.A (GND), J1.Z (GND), J2.1, JP1.1 (A), JP2.1 (A), JP3.1 (A), JP4.1 (A), RN1.1 (common), RN2.1 (common), RN3.1 (common), RN4.1 (common), SW2.2 (B), SW3.2 (B), SW4.2, U1.14 (GND), U2.10 (GND), U3.10 (GND), U4.10 (GND), U5.10 (GND)
unnamed: D1.1 (K), RN2.2 (R1)
unnamed: D1.2 (A), U2.18 (Y0)
unnamed: D2.1 (K), RN2.3 (R2)
unnamed: D2.2 (A), U2.17 (Y1)
unnamed: D3.1 (K), RN2.4 (R3)
unnamed: D3.2 (A), U2.16 (Y2)
unnamed: D4.1 (K), RN2.5 (R4)
unnamed: D4.2 (A), U2.15 (Y3)
unnamed: D5.1 (K), RN2.6 (R5)
unnamed: D5.2 (A), U2.14 (Y4)
unnamed: D6.1 (K), RN2.7 (R6)
unnamed: D6.2 (A), U2.13 (Y5)
unnamed: D7.1 (K), RN2.8 (R7)
unnamed: D7.2 (A), U2.12 (Y6)
unnamed: D8.1 (K), RN2.9 (R8)
unnamed: D8.2 (A), U2.11 (Y7)
unnamed: D9.1 (K), RN1.2 (R1)
unnamed: D9.2 (A), U3.19 (Q0)
unnamed: D10.1 (K), RN1.3 (R2)
unnamed: D10.2 (A), U3.18 (Q1)
unnamed: D11.1 (K), RN1.4 (R3)
unnamed: D11.2 (A), U3.17 (Q2)
unnamed: D12.1 (K), RN1.5 (R4)
unnamed: D12.2 (A), U3.16 (Q3)
unnamed: D13.1 (K), RN1.6 (R5)
unnamed: D13.2 (A), U3.15 (Q4)
unnamed: D14.1 (K), RN1.7 (R6)
unnamed: D14.2 (A), U3.14 (Q5)
unnamed: D15.1 (K), RN1.8 (R7)
unnamed: D15.2 (A), U3.13 (Q6)
unnamed: D16.1 (K), RN1.9 (R8)
unnamed: D16.2 (A), U3.12 (Q7)
unnamed: D17.1 (K), RN3.2 (R1)
unnamed: D17.2 (A), U4.19 (Q0)
unnamed: D18.1 (K), RN3.3 (R2)
unnamed: D18.2 (A), U4.18 (Q1)
unnamed: D19.1 (K), RN3.4 (R3)
unnamed: D19.2 (A), U4.17 (Q2)
unnamed: D20.1 (K), RN3.5 (R4)
unnamed: D20.2 (A), U4.16 (Q3)
unnamed: D21.1 (K), RN3.6 (R5)
unnamed: D21.2 (A), U4.15 (Q4)
unnamed: D22.1 (K), RN3.7 (R6)
unnamed: D22.2 (A), U4.14 (Q5)
unnamed: D23.1 (K), RN3.8 (R7)
unnamed: D23.2 (A), U4.13 (Q6)
unnamed: D24.1 (K), RN3.9 (R8)
unnamed: D24.2 (A), U4.12 (Q7)
unnamed: D25.1 (K), RN4.2 (R1)
unnamed: D25.2 (A), U5.19 (Q0)
unnamed: D26.1 (K), RN4.3 (R2)
unnamed: D26.2 (A), U5.18 (Q1)
unnamed: D27.1 (K), RN4.4 (R3)
unnamed: D27.2 (A), U5.17 (Q2)
unnamed: D28.1 (K), RN4.5 (R4)
unnamed: D28.2 (A), U5.16 (Q3)
unnamed: D29.1 (K), RN4.6 (R5)
unnamed: D29.2 (A), U5.15 (Q4)
unnamed: D30.1 (K), RN4.7 (R6)
unnamed: D30.2 (A), U5.14 (Q5)
unnamed: D31.1 (K), RN4.8 (R7)
unnamed: D31.2 (A), U5.13 (Q6)
unnamed: D32.1 (K), RN4.9 (R8)
unnamed: D32.2 (A), U5.12 (Q7)
unnamed: JP1.2 (C), U2.1 (G1), U2.19 (G2)
unnamed: JP2.2 (C), U3.1 (OE)
unnamed: JP3.2 (C), U4.1 (OE)
unnamed: JP4.2 (C), U5.1 (OE)
unnamed: SW1.1 (A), SW2.3 (C)
ROM_A13: R1.2, SW1.4 (A), SW2.1 (A), U1.26 (A13)
ROM_A14: R2.2, SW3.1 (A), U1.1 (A14)
VCC: C1.1, C2.1, C3.1, C4.1, C5.1, C6.1, J1.2 (+5V), J1.3 (+5V), J2.2, JP1.3 (B), JP2.3 (B), JP3.3 (B), JP4.3 (B), R1.1, R2.1, U1.27 (~WE), U1.28 (VCC), U2.20 (VCC), U3.20 (VCC), U4.20 (VCC), U5.20 (VCC)
~EXROM: J1.9 (~EXROM), SW1.5 (B), U2.4 (A2)
~GAME: J1.8 (~GAME), SW1.2 (B), U2.3 (A1)
~RESET: J1.C (~RESET), SW4.1, U2.2 (A0)
~ROMH: J1.B (~ROMH), SW2.6 (C)
~ROML: J1.11 (~ROML), SW2.4 (A)
~ROM_CS: SW2.5 (B), U1.20 (~CS), U1.22 (~OE)

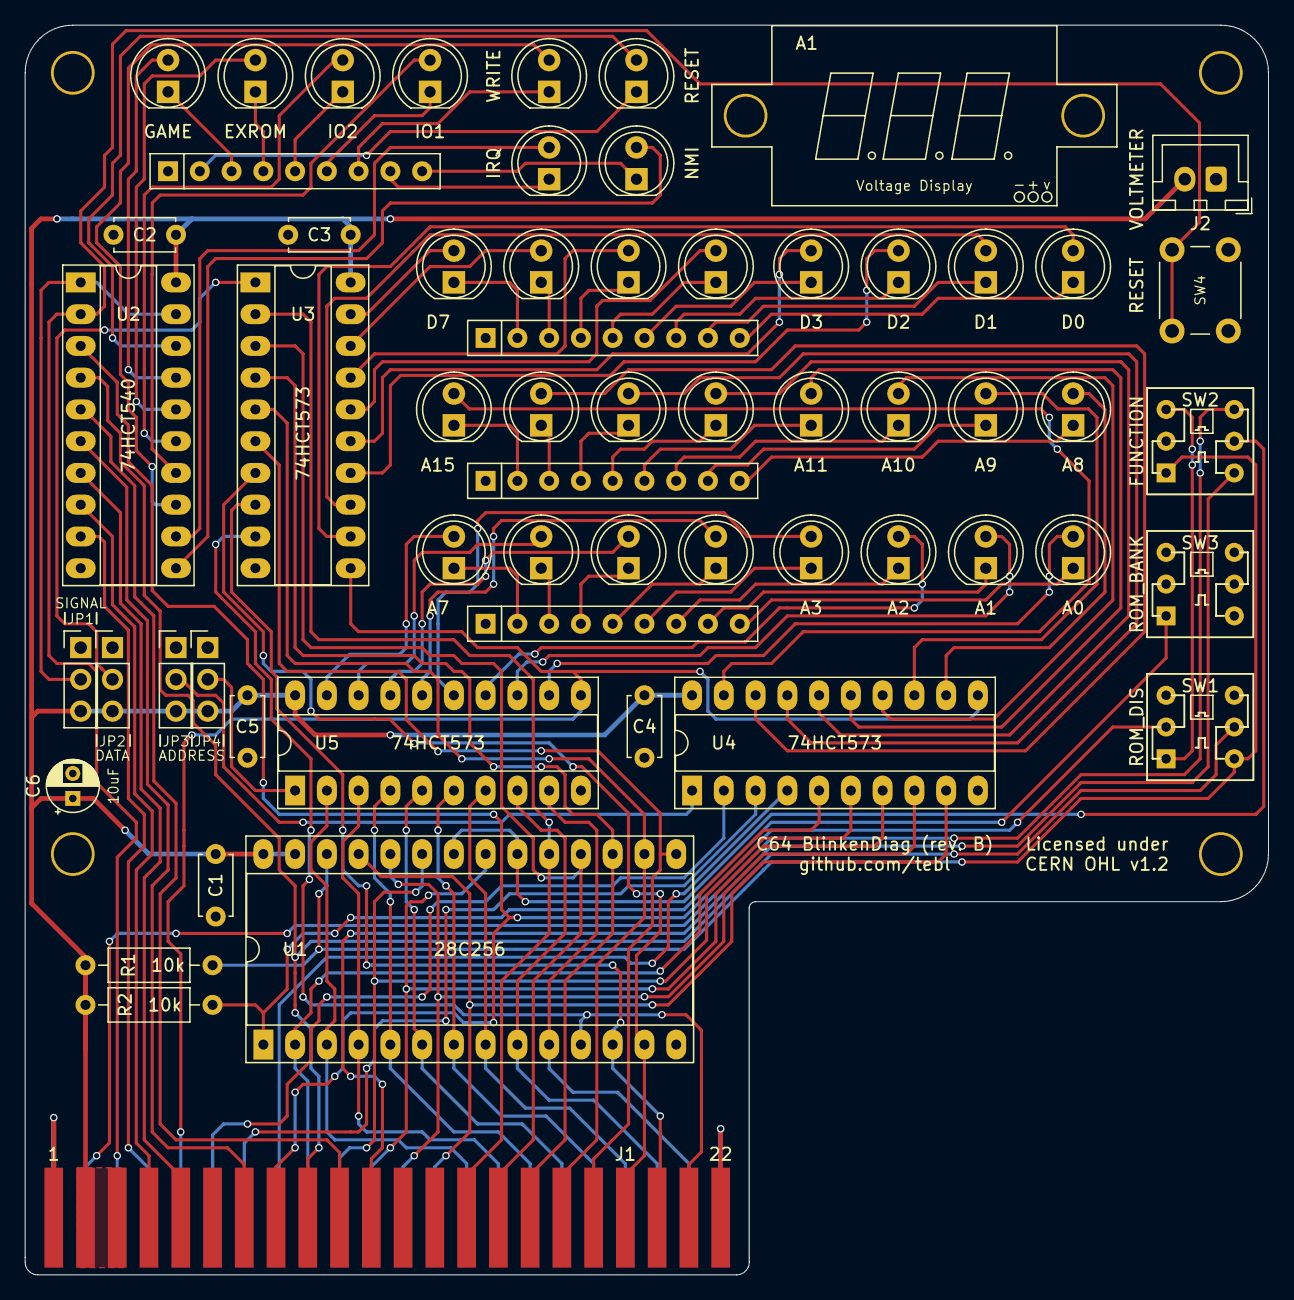
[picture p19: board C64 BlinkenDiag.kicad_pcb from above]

Board: 2 copper layers, 99.4 x 99.9 mm, 64 parts (0 on the bottom side), 109 nets.

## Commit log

2021-02-17 Added cartridge schematic
    [C64 BlinkenDiag.sch]
2021-02-17 Added switch to disable ROM
    [C64 BlinkenDiag.sch]
2021-02-17 Added voltmeter module and mounting library
    [C64 BlinkenDiag.sch]
2021-02-17 Assign footprints
    [C64 BlinkenDiag.sch]
2021-02-17 Edges and mounting added
    [C64 BlinkenDiag.kicad_pcb, C64 BlinkenDiag.sch]
2021-02-19 Did a layout
    [C64 BlinkenDiag.kicad_pcb, C64 BlinkenDiag.sch]
2021-02-19 Tweaked silkscreen and gerber export
    [C64 BlinkenDiag-B_Cu.gbl, C64 BlinkenDiag-B_Mask.gbs, C64 BlinkenDiag-B_SilkS.gbo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]
2021-02-22 Add PCB preview
    [C64 BlinkenDiag.kicad_pcb]
2021-03-15 Added faceplate and changed ROM_EN to ROM_DIS
    [C64 BlinkenDiag Faceplate-B_Cu.gbl, C64 BlinkenDiag Faceplate-B_Mask.gbs, C64 BlinkenDiag Faceplate-B_SilkS.gbo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]
2021-03-16 Added BOM
2021-03-16 Added orientation for the black switches
    [C64 BlinkenDiag-B_Cu.gbl, C64 BlinkenDiag-B_Mask.gbs, C64 BlinkenDiag-B_SilkS.gbo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]
2021-03-17 Updated gerber files
    [C64 BlinkenDiag Faceplate-B_Cu.gbl, C64 BlinkenDiag Faceplate-B_Mask.gbs, C64 BlinkenDiag Faceplate-B_SilkS.gbo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]
2021-03-17 Added PCBway links
    [C64 BlinkenDiag.kicad_pcb]
2021-04-09 Improved switch description slightly

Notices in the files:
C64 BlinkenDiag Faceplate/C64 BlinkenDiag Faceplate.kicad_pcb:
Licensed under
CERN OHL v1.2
